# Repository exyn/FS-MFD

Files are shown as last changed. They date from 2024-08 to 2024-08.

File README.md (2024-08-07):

## FS-MFD
Simple USB Flight-Simulator MFD designed with KiCad for use with DCS/MSFS. Cheaper than commercial alternatives and every possibility to customise.<br>
Easy-to-get components, and everything through-hole, to make it easy to solder for anyone.<br>
One board with all components and the PCB ordered and delivered from JLCPCB was about $21 for our first run.<br>
Accompanying 3D-printable enclosure (see Mechanics).<br>

#### Features:

* 20 x Tactile Switches (Buttons)
* 2 x Rotary Encoder (with push-button)
* 2 x Toggle Switch/Slide Switch
* Raspberry Pi Pico control board/USB interface
* Simple SW project for use as a general Gamepad USB device available as source and binary.
<br>
For any questions send an e-mail to gustaf.lindstroem@gmail.com. There will be more projects to come.<br>
There might be a future version of this board with display (as an option maybe). It's designed with VR use in mind first though.
Should you have any specific modification request send it to us and we'll see what we can do.<br>
If our material is used for anything please give a simple credit by linking here. Everything is open to use, modify etc. of course though. Only requirement is that the derivative works is also released open source to the public.
<br><br>

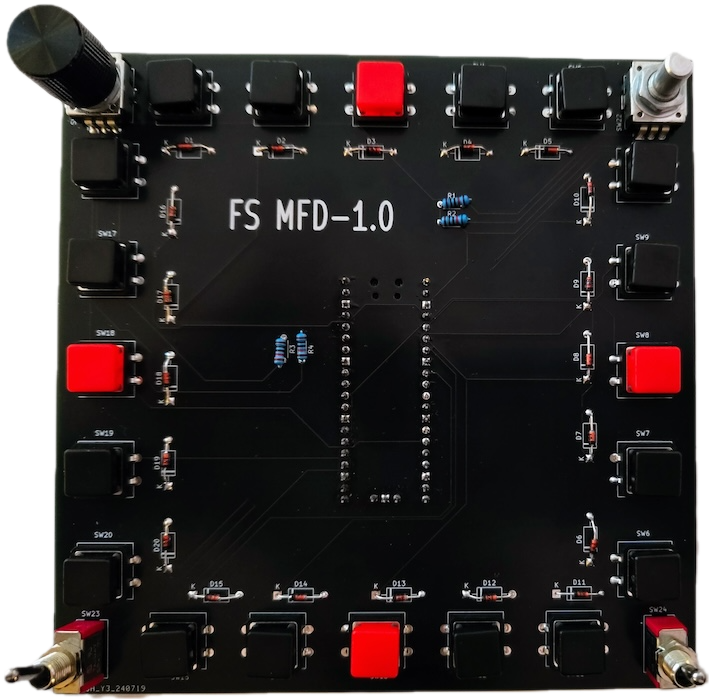
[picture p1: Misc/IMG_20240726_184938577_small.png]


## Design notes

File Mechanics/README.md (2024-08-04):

## Mechanics

Project including the files needed to generate compatible files for 3D-printing of the enclosure as well as
already exported files to be used directly to print it.

# First look
The enclosure is starting to take form.<br>
We also have thoughts about making it easy to mount the MFD to aluminium rails to integrate them into a larger simulator design. All files will be available here for printing and modifications.<br><br>

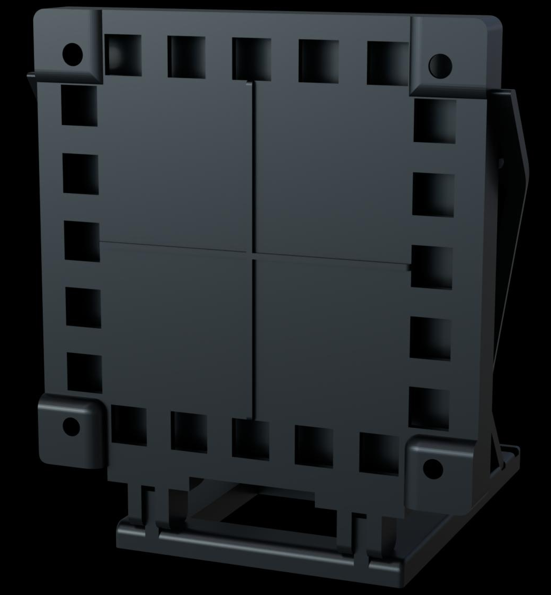
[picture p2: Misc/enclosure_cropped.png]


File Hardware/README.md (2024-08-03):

## Hardware

KiCad project and exported Gerber files to use directly to order boards.

* Two-layer board, 142x142 mm, nothing special or unusual regarding vias, traces, pads, drilling or otherwise.
* Gerber/drill files have been used with JLCPCB to order PCB:s that are exactly as expected (their default options for a two-layer board, only thing requested was black solder-mask.
* The Gerber/drill files currently uploaded correspond to revision A of the board. There are a couple of minor changes that will be made in revision B that should make it into any files used to make PCB:s. It is nothing fatal but especially the toggle switch footprints need to be changed.
* The KiCad project also is at revision A. See above comment.
* There is a BOM generated with KiCad. The board works with many different manufacturers of cheap switches for instance though so it's worth checking out before getting anything more expensive. Same thing regarding the EC11 encoders. A big point here was to do a simple and cheap board to make it as available as possible.
* There might be a future revision prepared for a display, that has not really been decided yet though since this board is meant for VR first.
* The libraries imported to the project will be put in a libraries directory to make things a bit cleaner. Expect most of these minor things in a revision B update coming soon.

<br>

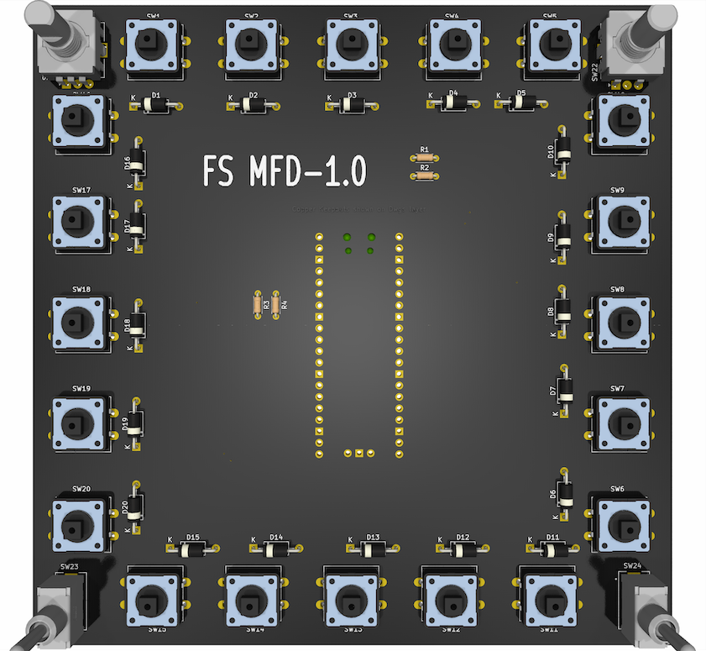
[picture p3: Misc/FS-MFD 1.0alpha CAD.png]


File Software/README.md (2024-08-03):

## Software

Arduino IDE project with full functionality as well as binaries ready to flash the Raspberry Pi Pico with (TBD, should make it here soon).<br>
A somewhat more general project that does not require Aruino IDE to build might be available further on.
<br><br>
A first version making it possible to use everything on the board except the A/B encoder signals is available now with <br>
the Pi Pico appearing as a USB Gamepad to any general high-level operating system. Testing this in DCS has been done and is working<br>
as expected. As soon as it has been cleaned up a little bit it will be posted here!

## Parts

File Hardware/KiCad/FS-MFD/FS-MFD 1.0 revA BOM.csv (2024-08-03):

Reference | Value | Datasheet | Footprint | Qty | DNP
D1,D2,D3,D4,D5,D6,D7,D8,D9,D10,D11,D12,D13,D14,D15,D16,D17,D18,D19,D20 | D | ~ | Diode_THT:D_A-405_P10.16mm_Horizontal | 20
R1,R2,R3,R4 | 10k | ~ | Resistor_THT:R_Axial_DIN0204_L3.6mm_D1.6mm_P5.08mm_Horizontal | 4
SW1,SW2,SW3,SW4,SW5,SW6,SW7,SW8,SW9,SW10,SW11,SW12,SW13,SW14,SW15,SW16,SW17,SW18,SW19,SW20 | SW_Push | ~ | Button_Switch_THT:SW_PUSH-12mm | 20
SW21,SW22 | RotaryEncoder_Switch | ~ | Rotary_Encoder:RotaryEncoder_Alps_EC11E-Switch_Vertical_H20mm | 2
SW23,SW24 | SW_SPDT | ~ | 100SP1T1B4M2QE:SW_100SP1T1B4M2QE | 2
U1 | Pico |  | MCU_RaspberryPi_and_Boards:RPi_Pico_SMD_TH | 1

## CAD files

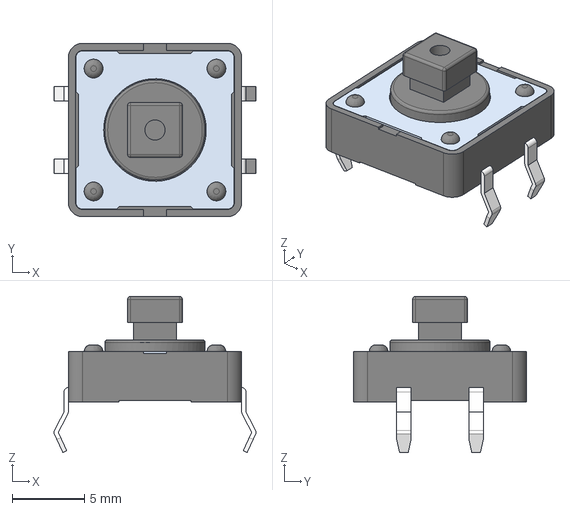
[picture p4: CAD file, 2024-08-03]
Hardware/KiCad/FS-MFD/WE_430466073726_Libraries/430466073726 (rev1).stp
14.0 x 12.0 x 10.8 mm

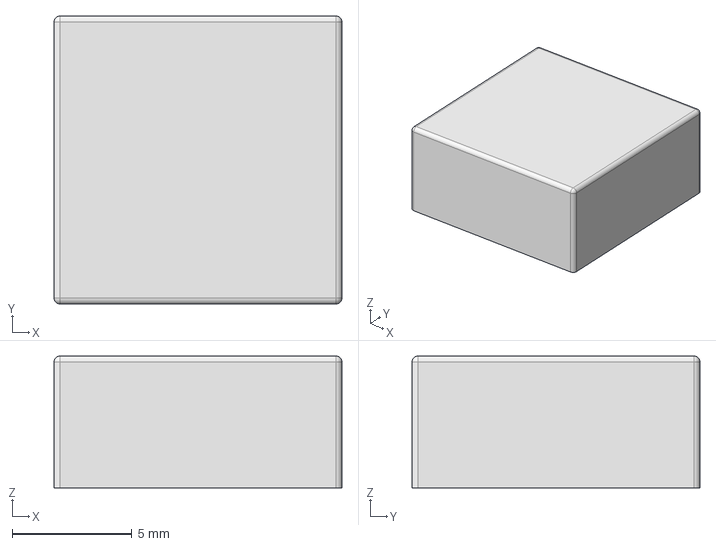
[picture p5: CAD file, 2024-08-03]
Hardware/KiCad/FS-MFD/WE_714301050_Libraries/714301050 (rev1).stp
12.0 x 12.0 x 5.50 mm

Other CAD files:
Hardware/KiCad/FS-MFD/KiCad-RP-Pico-main/SketchUp Model/Pico.skp
Hardware/KiCad/FS-MFD/WE_430466073726_Libraries/430466073726 (rev1).igs
Hardware/KiCad/FS-MFD/WE_714301050_Libraries/714301050 (rev1).igs

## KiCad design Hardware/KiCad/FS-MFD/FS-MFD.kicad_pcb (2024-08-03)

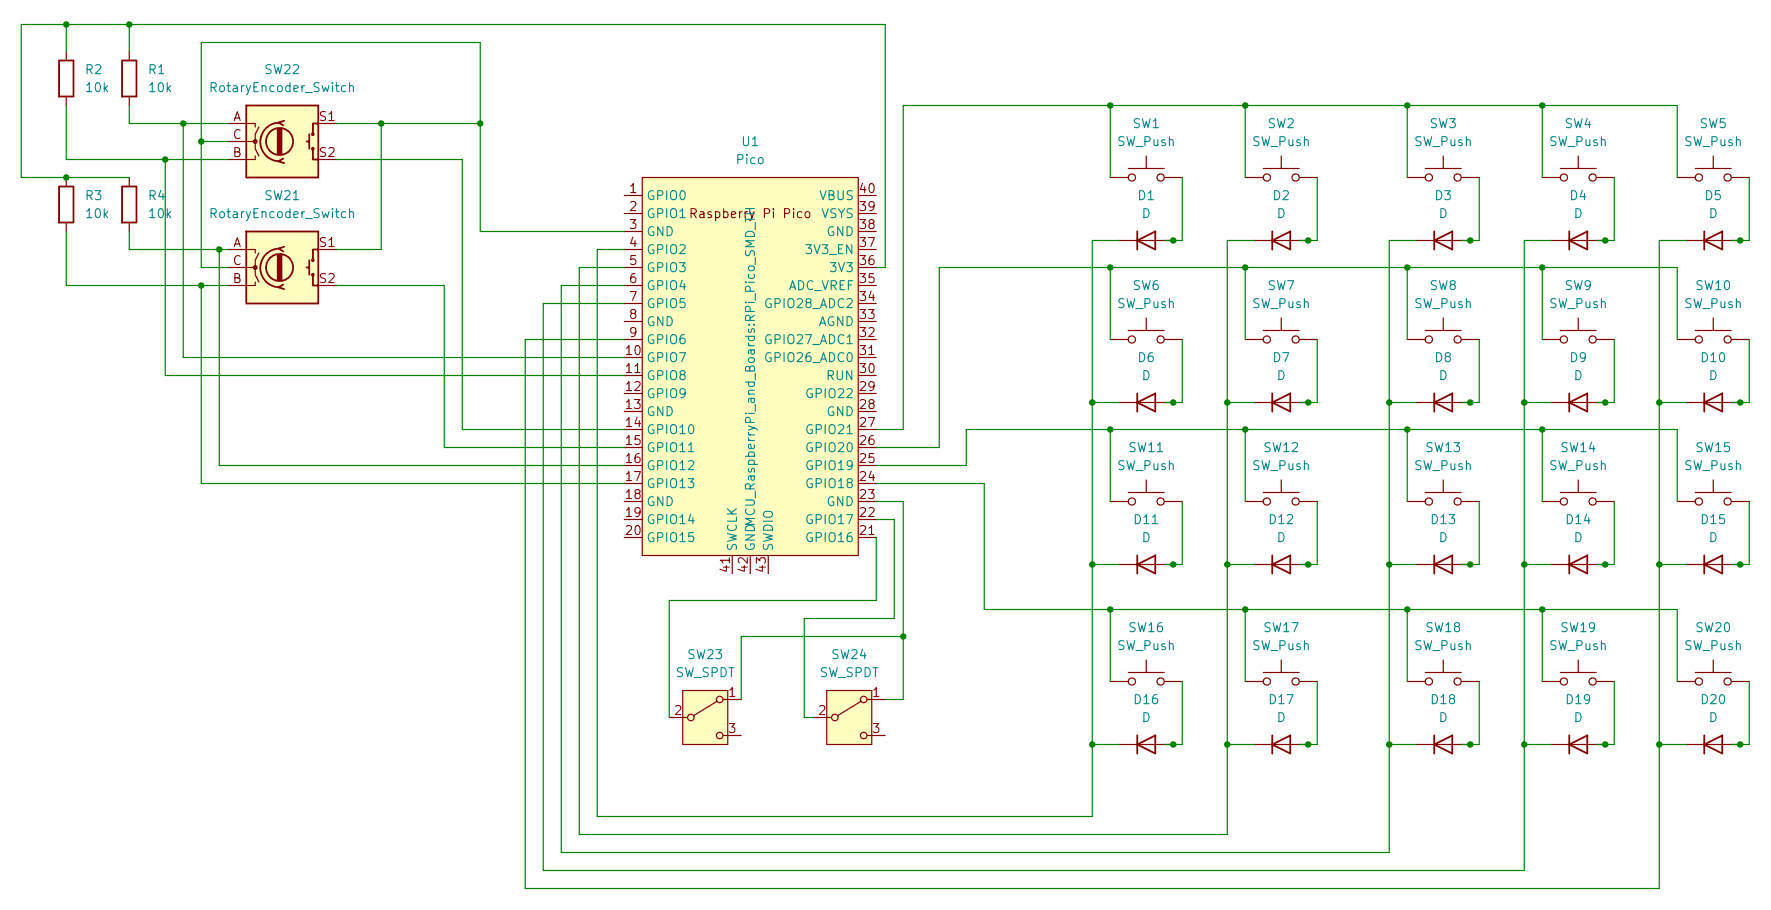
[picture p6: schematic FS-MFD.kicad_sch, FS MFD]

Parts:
D1, D2, D3, D4, D5, D6, D7, D8, D9, D10, D11, D12, D13, D14, D15, D16, D17, D18, D19, D20: D; D_A-405_P10.16mm_Horizontal
R1, R2, R3, R4: 10k; R_Axial_DIN0204_L3.6mm_D1.6mm_P5.08mm_Horizontal
SW1, SW2, SW3, SW4, SW5, SW6, SW7, SW8, SW9, SW10, SW11, SW12, SW13, SW14, SW15, SW16, SW17, SW18, SW19, SW20: SW_Push; SW_PUSH-12mm
SW21, SW22: RotaryEncoder_Switch; RotaryEncoder_Alps_EC11E-Switch_Vertical_H20mm
SW23, SW24: SW_SPDT; SW_100SP1T1B4M2QE
U1: Pico; RPi_Pico_SMD_TH

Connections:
unnamed: D1.2 (A), SW1.2
unnamed: D1.1 (K), D6.1 (K), D11.1 (K), D16.1 (K), U1.4 (GPIO2)
unnamed: D2.2 (A), SW2.2
unnamed: D3.2 (A), SW3.2
unnamed: D4.2 (A), SW4.2
unnamed: D5.2 (A), SW5.2
unnamed: D6.2 (A), SW6.2
unnamed: D7.2 (A), SW7.2
unnamed: D8.2 (A), SW8.2
unnamed: D9.2 (A), SW9.2
unnamed: D10.2 (A), SW10.2
unnamed: D5.1 (K), D10.1 (K), D15.1 (K), D20.1 (K), U1.9 (GPIO6)
unnamed: D11.2 (A), SW11.2
unnamed: D12.2 (A), SW12.2
unnamed: D2.1 (K), D7.1 (K), D12.1 (K), D17.1 (K), U1.5 (GPIO3)
unnamed: D13.2 (A), SW13.2
unnamed: D3.1 (K), D8.1 (K), D13.1 (K), D18.1 (K), U1.6 (GPIO4)
unnamed: D14.2 (A), SW14.2
unnamed: D4.1 (K), D9.1 (K), D14.1 (K), D19.1 (K), U1.7 (GPIO5)
unnamed: D15.2 (A), SW15.2
unnamed: D16.2 (A), SW16.2
unnamed: D17.2 (A), SW17.2
unnamed: D18.2 (A), SW18.2
unnamed: D19.2 (A), SW19.2
unnamed: D20.2 (A), SW20.2
unnamed: SW21.C, SW21.S1, SW22.C, SW22.S1, U1.3 (GND)
unnamed: SW23.1 (A), SW24.1 (A), U1.23 (GND)
unnamed: SW23.2 (B), U1.21 (GPIO16)
unnamed: SW24.2 (B), U1.22 (GPIO17)
unnamed: R1.1, R2.1, R3.1, R4.1, U1.36 (3V3)
unnamed: R1.2, SW22.A, U1.10 (GPIO7)
unnamed: R2.2, SW22.B, U1.11 (GPIO8)
unnamed: SW22.S2, U1.14 (GPIO10)
unnamed: SW21.S2, U1.15 (GPIO11)
unnamed: R4.2, SW21.A, U1.16 (GPIO12)
unnamed: R3.2, SW21.B, U1.17 (GPIO13)
unnamed: SW16.1, SW17.1, SW18.1, SW19.1, SW20.1, U1.24 (GPIO18)
unnamed: SW11.1, SW12.1, SW13.1, SW14.1, SW15.1, U1.25 (GPIO19)
unnamed: SW6.1, SW7.1, SW8.1, SW9.1, SW10.1, U1.26 (GPIO20)
unnamed: SW1.1, SW2.1, SW3.1, SW4.1, SW5.1, U1.27 (GPIO21)

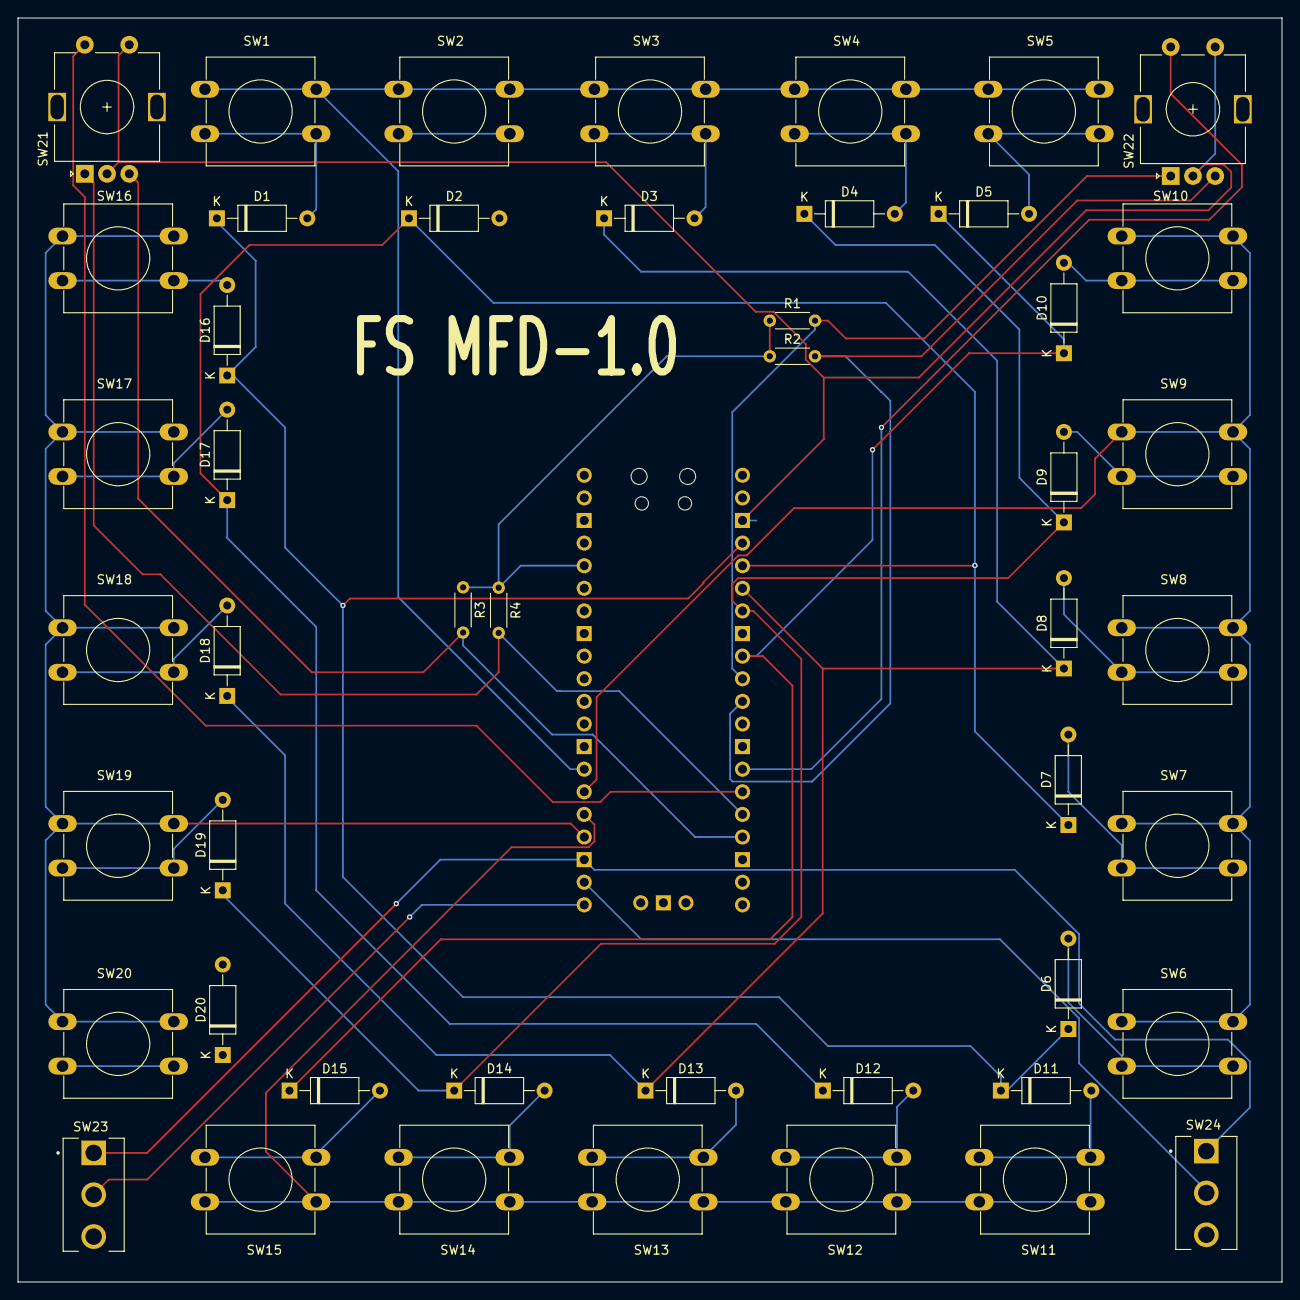
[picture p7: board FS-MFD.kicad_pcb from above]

Board: 2 copper layers, 142.0 x 142.0 mm, 49 parts (1 on the bottom side), 40 nets.

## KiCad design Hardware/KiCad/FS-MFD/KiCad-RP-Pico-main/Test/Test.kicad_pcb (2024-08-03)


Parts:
J1, J2: Conn_01x20; PinSocket_1x20_P1.00mm_Vertical
J3: Conn_01x03; PinSocket_1x03_P1.00mm_Vertical
U1: Pico; RPi_Pico_SMD_TH

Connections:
GND: J1.3, J1.8, J1.13, J1.18, J2.3, J2.13, J2.18, J3.2, U1.3 (GND), U1.8 (GND), U1.13 (GND), U1.18 (GND), U1.23 (GND), U1.28 (GND), U1.38 (GND), U1.42 (GND)
unnamed: J1.1, U1.1 (GPIO0)
unnamed: J1.2, U1.2 (GPIO1)
unnamed: J1.4, U1.4 (GPIO2)
unnamed: J1.5, U1.5 (GPIO3)
unnamed: J1.6, U1.6 (GPIO4)
unnamed: J1.7, U1.7 (GPIO5)
unnamed: J1.9, U1.9 (GPIO6)
unnamed: J1.10, U1.10 (GPIO7)
unnamed: J1.11, U1.11 (GPIO8)
unnamed: J1.12, U1.12 (GPIO9)
unnamed: J1.14, U1.14 (GPIO10)
unnamed: J1.15, U1.15 (GPIO11)
unnamed: J1.16, U1.16 (GPIO12)
unnamed: J1.17, U1.17 (GPIO13)
unnamed: J1.19, U1.19 (GPIO14)
unnamed: J1.20, U1.20 (GPIO15)
unnamed: J2.1, U1.40 (VBUS)
unnamed: J2.2, U1.39 (VSYS)
unnamed: J2.4, U1.37 (3V3_EN)
unnamed: J2.5, U1.36 (3V3)
unnamed: J2.6, U1.35 (ADC_VREF)
unnamed: J2.7, U1.34 (GPIO28_ADC2)
unnamed: J2.8, U1.33 (AGND)
unnamed: J2.9, U1.32 (GPIO27_ADC1)
unnamed: J2.10, U1.31 (GPIO26_ADC0)
unnamed: J2.11, U1.30 (RUN)
unnamed: J2.12, U1.29 (GPIO22)
unnamed: J2.14, U1.27 (GPIO21)
unnamed: J2.15, U1.26 (GPIO20)
unnamed: J2.16, U1.25 (GPIO19)
unnamed: J2.17, U1.24 (GPIO18)
unnamed: J2.19, U1.22 (GPIO17)
unnamed: J2.20, U1.21 (GPIO16)
unnamed: J3.1, U1.43 (SWDIO)
unnamed: J3.3, U1.41 (SWCLK)


Board: 2 copper layers, 43.0 x 65.0 mm, 4 parts (0 on the bottom side), 36 nets.

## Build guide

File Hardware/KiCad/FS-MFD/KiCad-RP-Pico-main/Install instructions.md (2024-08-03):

# Install instructions

## 1. Copy the files locally

Copy the `RP-Pico Libraries` folder wherever you like on your computer.

## 2. Install the Raspberry Pi Pico board schema symbol

Use the `KiCad | Preferences | Manage Symbol Libraries...` command to manage the symbol library:



then select the global tab and click on the folder button:



navigate to the `RP-Pico Libraries` folder, select the `MCU_RaspberryPi_and_Boards.kicad_sym` file and open it:



et voilà, the first step is completed:



You can now close the symbol libraries manager window.

## 3. Install the Raspberry Pi Pico board footprint

You can use a similar approach to add the footprint to the footprint libraries manager, but I've found some issues that I've solved using the footprint editor, so here are the steps I suggest you to follow:

Open the footprint editor



wait for the footprints to load... then use the `File | Add Library` command:



confirm the `Global` choice:



and select the `MCU_RaspberriPi_and_Boards.pretty` folder (yes, the folder represent a footprint library on KiCad):



Now the library is installed on KiCad with the Raspberry Pi Pico footprint (double click on it to see it on the editor pane):



Don't close the windows as the next step start from here.

## 4. Install the Raspberry Pi Pico board footprint 3D visual

If not already open, open the the footprint editor

symbol library manager

double click on the `RPi_Pico_SMD_TH` footprint from the `MCU_RaspberriPi_and_Boards` library and then click on the `Footprint properties` icon:



In the footprint properties window, first select the `3D Settings` tab. Please note that the preview shows only the PCB board with the footprint added on step 3, without any 3D representation of the Raspberry Pi Pico board. Now click on the folder icon to add the 3D model:



Navigate to the `RP-Pico Libraries` folder, select the `Pico.wrl` file and wait until the model is shown in the right panel, then confirm with OK:



The model is already scaled and translated to match the footprint:



now close the `Footprint Properties` window, and the `Footprint Editor`, obviously saving the changes.

## Conclusion

Now that you've installed the schema and footprint and added the 3D model to the footprint, you can use the Raspberry Pi Pico board on your KiCad projects.

I've also added a test KiCad Project on the `Test` folder, that you can use to see an example of it.

Have fun!

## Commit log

2024-07-26 Create README.md
    Make place for KiCad project.
2024-07-26 Update README.md
    Smaller image of board.
2024-08-01 Update README.md
    Give a sense of the cost per board.
2024-08-03 Add KiCad project
    [430466073726 (rev1).igs, 430466073726 (rev1).stp, 714301050 (rev1).igs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]
2024-08-03 Add ploted Gerber and drill files
    These files correspond with the first PCB:s produced, revision A, and there are at least two minor things to change there.
    Nothing that means connections are wrong or something else more serious though. See revision B of the board for details.
    [FS-MFD-B_Cu.gbl, FS-MFD-B_Mask.gbs, FS-MFD-B_Silkscreen.gbo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]
2024-08-03 Update README.md
    BOM
2024-08-03 Add files via upload
    Add basic BOM. Will be updated with correct references to the Würth buttons/caps for instance but this is a start.
    [FS-MFD 1.0 revA BOM.csv]
2024-08-04 Add files via upload
    Enclosure almost done.
